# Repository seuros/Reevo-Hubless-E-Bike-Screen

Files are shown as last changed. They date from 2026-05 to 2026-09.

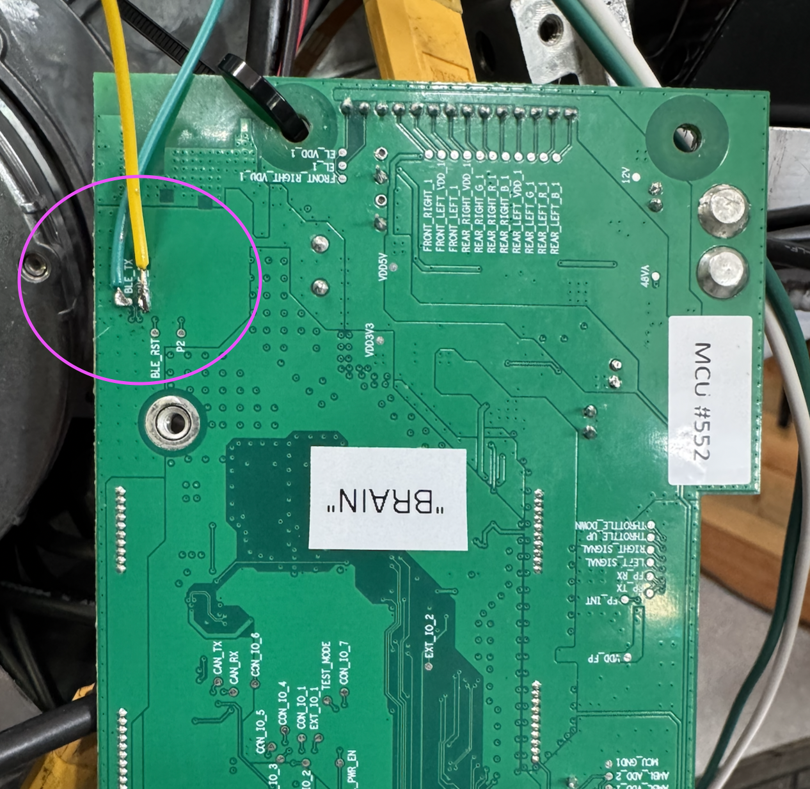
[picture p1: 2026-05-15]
docs/ble_solder_points.png

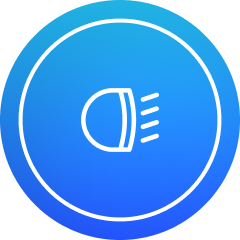
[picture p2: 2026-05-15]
firmware/tools/source_images/front_light_off.png

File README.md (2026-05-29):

# Reevo Display

A custom dashboard for the **Beno Reevo** hubless ebike. The company abandoned the project
and the original phone app is dead — this project replaces the entire app with
an ESP32-S3 touchscreen that talks directly to the bike over BLE. No cloud, no
SIM, no account.

If you own a Reevo and a soldering iron and twenty bucks, you can have a
working dashboard again.

---

## What you get

- Live speedometer (green 7-segment), battery %, trip odometer with reset
- Manual control of headlight, badge light, kickstand lock, assist level
- Touch-PIN unlock when you lock the bike
- **Brake warn** — flashes headlight + badge in alternation when you brake
- **PAS auto-timeout** — drops pedal assist to 0 after 10 min idle so the
  bike never takes off when you push it through the garage
- **Master code recovery** if you forget your PIN
- Built-in **Wi-Fi access point + web console** for sending raw BLE commands,
  resetting your PIN, recoloring the screen, and viewing a full setup manual

---

## Hardware

### Display (required)

The default target is the **Freenove FNK0104B** ESP32-S3 board with 2.8″
capacitive touchscreen.

> Buy: <https://amzn.to/4dJlGMW>

Specs that matter:
- ESP32-S3 with 16 MB flash, 8 MB PSRAM
- 240×320 ILI9341 IPS panel
- FT6336U capacitive touch
- Native USB-C (programming + power)
- 4-pin UART header (5V, GND, TX, RX)

If you bought a different "CYD" board, see [Using a different display](#using-a-different-display) below.

### Power

The display takes 5V via USB-C. Three ways to power it:

1. **Recommended (clean):** Solder to a labeled **5V** and **GND** pad on
   the bike's mainboard and run those to the **5V** and **GND** pins of the
   display's UART header. The board is fully silk-screened, so suitable 5V
   and GND points are easy to find — just confirm with a multimeter that
   the pad reads ~5V (not the 12V/48V rail) before you connect it. This is
   what my (Seth's) build does — the screen comes on when the bike does and
   goes off when the battery is removed.
2. **USB-C battery brick** — easy, less clean.
3. Any other power source, using a cheap buck converter to step down to 5V

> **The display's 4-pin UART header carries two unrelated things.** The
> **5V/GND** pins are just power (above). The **TX/RX** pins are the
> optional BLE-debug data tap described below. They're independent — you
> can wire power without the data tap, or vice versa. Nothing on this cable
> controls the bike: the firmware only ever *listens* on RX. It cannot
> send anything to the bike over this connection.

### Enclosure (optional, 3D-printable)

A two-piece printable case for the Freenove FNK0104B board lives in
[`screen_enclosure/`](screen_enclosure/):

| File | Part |
|---|---|
| [`Reevo_Screen_Top.stl`](screen_enclosure/Reevo_Screen_Top.stl) | Front bezel — frames the screen, snaps onto the bottom |
| [`Reevo_Screen_Bottom.stl`](screen_enclosure/Reevo_Screen_Bottom.stl) | Rear shell — holds the board, routes the UART cable out |

Both files preview in 3D right on GitHub — click either one to spin it
around before you print.

**Printing notes.** The case is **not water-resistant** — and honestly you
shouldn't ride a Reevo in the rain anyway. Treat the bike like the
collector's item it now is: ride it carefully and seldom. Because of that,
filament choice isn't critical — **PLA or PETG both work fine**. (The one
exception: don't leave a PLA print baking in direct desert sun, à la
Arizona — it'll soften.)

For reference, mine (Seth's) is printed in **MatterHackers NylonX** at
**0.24 mm layer height, 3 outer walls, 25% infill** — overkill that'll
outlast every other piece of plastic on the bike. NylonX is a
carbon-fiber-filled nylon, so it needs a **hardened nozzle** and an
**enclosed printer**. Don't feel obligated to match that — use the
filament and machine you already know and like.

### BLE pairing — read this before you flash

The bike's BLE module (RN4870) ships with passkey `111111`. **That default
only works if the bike has never been paired with the original Reevo app.**
The first time the original app paired with your bike, it rotated the
passkey to a value only the app knew. You can't factory-reset that without
already being able to bond — chicken and egg.

So, in order of likelihood, here's how you actually find the passkey:

- **A.** You wrote it down when you first set the bike up. Rarest.
- **B.** It's stored somewhere on the device that originally paired. On
  macOS, *Keychain Access* sometimes has BLE pairing data (search for
  "Reevo" or the bike's MAC). iOS keeps it locked away inside the system.
  Worth a look, mileage will vary.
- **C.** Read it off the bike's BLE module debug UART. This sounds
  intimidating but it's actually how I recovered mine, and it's the
  reliable path for any bike that was ever paired with the original app.
  You would need to take the bike apart completely and remove the main
  board in the motor compartment. It's gnarly. It's scary. It's doable.
  Details below.

### Recovering the passkey via the UART (the real path for most bikes)

When anything tries to bond, the bike's RN4870 BLE module **prints the
real expected passkey to its debug UART**. You just have to read it. Solder
two thin wires to the **TX** and **GND** pads on the module — see
[`docs/ble_solder_points.png`](docs/ble_solder_points.png) for the exact
pads. (You only need the module's **TX**; the connection is read-only, so
its RX is never used.) While you've got the iron out and the bike open
(bullet C above — you'll have the mainboard exposed), it's the natural
moment to also grab a **5V** and **GND** pad for permanent screen power —
see [Power](#power).

There are two ways to read what it prints:

#### Easiest — read it right on the dashboard (no computer)

If you've already built the screen, it *is* your serial terminal. The
dashboard's **Diagnostics page** renders whatever the BLE module chatters
to its debug UART.

1. Run the module's **TX → the display's UART-header RX**, and tie **GND**
   to **GND**. (That's the data tap; powering the screen is a separate
   pair of pads — see [Power](#power).)
2. On the dashboard: Settings → **Diagnostics**.
3. Trigger a pair attempt from *anything* — the dashboard itself,
   **LightBlue** (iOS), **nRF Connect** (Android). Enter `111111` or any
   6-digit number; it'll fail, that's fine.
4. The 6-digit passkey scrolls onto the Diagnostics page.
5. Settings → Command Prompt → Start AP, join the Wi-Fi, browse to
   `192.168.4.1/`, and type `setblepin <the number>`. Tap **Re-pair bike**
   under Bluetooth. Done — and you never touched a computer.

#### Or — read it with a USB-UART adapter

Handy if you want the passkey *before* the screen is built.

1. Run the module's **TX** and **GND** to a USB-UART adapter (CP2102, FTDI,
   CH340 — any will do; adapter **RX ← module TX**). Open a serial terminal
   at **115200 baud, 8N1, no flow control**.
2. With the terminal listening, attempt to pair from anything and enter any
   6-digit number — it'll fail, but the module prints the real passkey.
3. Read the 6-digit number off the terminal, then `setblepin <number>` on
   the web prompt and **Re-pair bike**.

**You do not need to do any of this on a new, never-paired Reevo** — the
default `111111` works there. But for anything secondhand, plan on the
UART tap.

---

## Quick install (macOS / Linux)

If you've never touched any of this before:

```bash
git clone https://github.com/setha-maker/Reevo-Hubless-E-Bike-Screen.git
cd Reevo-Hubless-E-Bike-Screen
./scripts/install.sh
```

The script installs Homebrew (if needed), Python 3, PlatformIO, and the
asset-converter dependencies, then builds and flashes the firmware. Plug
the ESP32-S3 board into USB-C **before** running it.

## Manual install

Already have a working dev environment? Install requirements yourself:

```bash
pip install platformio Pillow numpy qrcode
```

Then:

```bash
cd firmware
python3 tools/image_to_rgb565.py    # generates src/assets.h bitmaps
pio run -e reevo -t upload          # builds and flashes
```

---

## Configuration

The repo ships a public template:

> **[`firmware/include/user_config.example.h`](firmware/include/user_config.example.h)**

The install script copies it to `firmware/include/user_config.h` on first
run. That copy is **gitignored** — your personal values never leak into
the public repo. If you're doing the install manually:

```bash
cp firmware/include/user_config.example.h firmware/include/user_config.h
```

Then edit `user_config.h`. The defines:

| Define | Default | What it does |
|---|---|---|
| `USER_DEFAULT_UNLOCK_PIN` | `"1234"` | Initial unlock PIN; rider can change at runtime |
| `USER_MASTER_PIN` | *(commented out)* | Optional owner-recovery master code. Uncomment in your personal copy if you want one. |
| `USER_DEFAULT_BLE_PASSKEY` | `"111111"` | RN4870 factory default. **Only correct for never-paired bikes** — for any used Reevo, recover the real passkey via the UART tap (see above) and set it at runtime with `setblepin`. |
| `USER_AP_SSID` | `"ReevoConnect"` | Initial Wi-Fi network the dashboard broadcasts |
| `USER_AP_PSK` | `"reevorider"` | Initial hotspot password (min 8 chars) |
| `USER_SPLASH_TAGLINE` | `"world's worst ebike"` | Text under the Reevo logo on the boot splash |

### Things you almost never need to recompile for

- **Unlock PIN** — change at runtime via the web `lockreset` command.
- **Wi-Fi SSID + password** — change at runtime via the web `changewifi`
  command. New values persist in NVS and survive reboots.
- **BLE pairing passkey** — change at runtime via the web `setblepin XXXXXX`
  command (e.g., once you've recovered the real passkey via the UART tap).
- **Splash colors** — change at runtime via the web `bgcolor` / `speedcolor`
  commands.

The compile-time defaults above are just what a fresh, factory-new flash
shows on first boot.

### The optional master PIN

`USER_MASTER_PIN` is commented out in the public template — the master-code
feature is fully compiled out for public builds. If you want a personal "I
forgot my code" backstop, uncomment the line in your `user_config.h` (which
is gitignored) and put a 4-digit code only you know. Don't commit it.

---

## Using a different display

If you bought a different ESP32-S3 CYD board, edit:

> **[`firmware/include/displays/display_config.h`](firmware/include/displays/display_config.h)**

This is the single source of truth for everything display-related: pin
numbers, panel driver, panel rotation, color order, touch chip, SPI
frequency. Common alternative profiles (Sunton CYD, generic ST7789, etc.)
are listed as commented-out blocks at the bottom — uncomment the one that
matches and recompile.

Things that vary between boards:
- SPI pins (MOSI, MISO, SCLK, CS, DC, RST, BL)
- Touch I²C pins (SDA, SCL, INT, RST)
- Panel driver chip (ILI9341 / ST7789 / ILI9488)
- BGR vs RGB color order
- Color inversion
- Backlight active-high vs active-low
- Native panel size and rotation

If your board isn't in the list, find its schematic and fill in the values.

---

## First-time use

1. Power on the bike.
2. Power on the dashboard.
3. Wait ~10 seconds. The dashboard scans for any BLE device with "REEVO"
   in its name and tries to bond with the configured passkey (default
   `111111`).
   - **Bond succeeds → live telemetry appears.** You're done.
   - **Bond fails / dashboard sits on "scan"** → your bike's passkey has
     been rotated away from the factory default. Use the UART recovery
     procedure above to read the real passkey, then `setblepin XXXXXX`
     from the web command prompt and tap **Re-pair bike**.
4. The default unlock PIN is `1234`. The first time you lock, the numpad
   will ask for it. Change it with the web `lockreset` command.

After that, everything that needs configuring can be done from the
dashboard itself — no recompiling.

---

## Built-in help

The dashboard's web command prompt has three giant text dumps you can read
right from your phone after joining the AP:

| Command | Contents |
|---|---|
| `newreevosetup` | Full end-user manual with troubleshooting tree |
| `how` | Complete BLE protocol reference (every command & register) |
| `story` | Claude's narrative of how this firmware came to be |

To get there: tap the gear icon on the main screen → **Command Prompt** →
**Start AP** → join the SSID (or scan the QR) → open the URL in any
browser → tap the chip for the command you want.

---

## Troubleshooting (short version)

Detailed guide: type `newreevosetup` on the web prompt.

| Problem | First thing to try |
|---|---|
| BLE won't connect | Settings → Bluetooth → Reset Default Pincode → Re-pair bike |
| Forgot your unlock PIN | Type the master code (whatever you set `USER_MASTER_PIN` to) |
| Screen won't wake | Tap it. Then power-cycle USB-C. |
| PAS won't engage | Tap the PAS pill to raise assist level; the timeout may have dropped it |
| BLE bond fails / "scan" forever | The bike's passkey isn't 111111 anymore. Solder UART tap → trigger a pair attempt from any BLE app → read the real 6-digit passkey from the module's debug output → `setblepin XXXXXX` on the web prompt. See the BLE pairing section above. |

---

## Project layout

```
firmware/
  include/
    user_config.example.h    ← public template (committed)
    user_config.h            ← your personal copy (gitignored — install
                                 script makes it from the example)
    displays/
      display_config.h       ← edit me if your board isn't a Freenove FNK0104B
    config.h, pins.h         ← derived from display_config.h
    lgfx_board.h             ← LovyanGFX panel/touch config
  src/                       ← the actual firmware
  tools/
    image_to_rgb565.py       ← bakes splash, icons, QR into src/assets.h
    source_images/           ← source PNGs the converter reads
docs/
  PROTOCOL.md                ← full BLE protocol reverse-engineering notes
  ble_solder_points.png      ← reference for the RN4870 UART tap
screen_enclosure/
  Reevo_Screen_Top.stl       ← 3D-printable front bezel
  Reevo_Screen_Bottom.stl    ← 3D-printable rear shell
scripts/
  install.sh                 ← macOS/Linux one-shot installer
```

---

## License

MIT. See [LICENSE](LICENSE).

This project is unaffiliated with Beno. Reevo is their trademark; the
hardware design is referenced only for interoperability after the company's
shutdown.

## Credits

Built by Seth Alvo, with assistance from Claude (Anthropic).
Special thanks to the prior Claude session that did the initial BLE
reverse-engineering, and to every Reevo owner who's still riding theirs.

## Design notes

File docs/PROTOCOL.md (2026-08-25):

# Reevo Bike BLE Protocol — Reverse Engineering Findings

Extracted from: `libapp.so` (Dart native code), `reevo.apk` DEX bytecode,
and live BLE capture via `reevo_repl.py` against a production Reevo unit.

---

## BLE Service & Characteristics

| Role | UUID |
|---|---|
| **ISSC Transparent UART Service** | `49535343-fe7d-4ae5-8fa9-9fafd205e455` |
| **Notify** (bike → phone) | `49535343-1e4d-4bd9-ba61-23c647249616` |
| **Write** (phone → bike) | `49535343-8841-43f4-a8d4-ecbe34729bb3` |
| **Flow Control** | `49535343-4c8a-39b3-2f49-511cff073b7e` |

**These four are the only characteristics the bike exposes**, confirmed by live
GATT scan. There is no separate PIN or fingerprint characteristic — settings,
authentication and fingerprint enrollment all ride this same transparent-UART
pipe as ASCII lines.

> **Correction (2026-08-25).** Earlier revisions listed two extra UUIDs, a
> "PIN Code Change" and a "Fingerprint / Auth" characteristic. Both were wrong —
> they came from a `libapp.so` string dump rather than a GATT scan, and are
> Windows `KNOWNFOLDERID` GUIDs pulled in by Flutter's desktop plugins. Removed.
> Thanks to Marek Żurawski for the finding.

The bike requires **BLE bonding/pairing** before any characteristic access.
The factory-default RN4870 passkey is **`111111`**, which works on
never-paired bikes. **The original Reevo app rotated the passkey on first
bond**, so any bike that's been paired before has a different value. To
recover an unknown passkey, tap the BLE module's debug UART (TX + GND) at
115200 baud and watch what it prints during a bonding attempt — the module
echoes the expected passkey in plain text. macOS `bleak` couldn't get past
the encrypted-subscribe step; NimBLE on ESP32-S3 works once the passkey
is correct.

---

## Line format (both directions)

All traffic on the Notify/Write characteristics is **ASCII** lines.

- **Outbound (write):** `0:C-<group>-<id>[,<value>]@`
- **Inbound (notify):** `<seq>:R-<group>-<id>,<value>` (no terminator)

The leading `0:` is constant on writes. Inbound `<seq>` is a sequence
counter that wraps; safe to ignore.

---

## Decoded commands (phone → bike)

Confirmed by toggling and watching the corresponding `R-1-*` register echo.

| Command | Action | R-* echo |
|---|---|---|
| `0:C-1-2@` | Engage lock (kickstand must be down) | `R-1-3 → 1` |
| `0:C-1-3@` | Unlock | `R-1-3 → 0` |
| `0:C-1-4@` | Headlight ON | `R-1-4 → 1` |
| `0:C-1-5@` | Headlight OFF | `R-1-4 → 0` |
| `0:C-1-10@` | Assist level UP (pasIncrease) | `R-1-10 += 1` |
| `0:C-1-11@` | Assist level DOWN (pasDecrease) | `R-1-10 -= 1` |
| `0:C-1-6@`  | Right turn signal ON  | `R-1-5 → 1` |
| `0:C-1-7@`  | Right turn signal OFF | `R-1-5 → 0` |
| `0:C-1-8@`  | Left turn signal ON | `R-1-6 → 1` |
| `0:C-1-9@`  | Left turn signal OFF  | `R-1-6 → 0` |
| `0:C-1-16@` | Badge light ON (the EL strip on the head badge) | *no echo* |
| `0:C-1-17@` | Badge light OFF | *no echo* |

> **Note on signals:** `C-1-6..9` are **not present** in the original
> Reevo app's command surface — the app only *reads* turn-signal state
> via `R-1-5/6` listeners and lets the rider toggle the signals via the
> bike's physical buttons. The commands work anyway on bike firmware
> revisions we've tested (verified empirically through the REPL). The
> dashboard's Brake Warn feature initially used them to alternate left
> and right while braking, but the bike's controller didn't tolerate the
> rapid back-and-forth well, so the feature now blinks the headlight
> and badge in unison instead. The signal commands are documented here
> in case they're useful later.

> **Note:** The Dart source labels `0:C-1-16/17` as `setThrottleOn/setThrottleOff`,
> but on the actual bike they drive the badge-light EL strip. Either the
> label in the APK is stale or this firmware revision repurposed the
> command. Trust the empirical behavior.

### Known but unmapped commands

These strings appear as outbound writes in the binary; their byte form
hasn't been confirmed against a live bike yet.

`C-0-1..6`, `C-1-12`, `C-2-2..5`, `C-2-7`. Probable mapping (from
proximity to Dart symbols): `startPasCalibration`,
`setMotionDetection On/Off`, `setGeofencingMode On/Off`,
`turnOnGSM`, `unregisterAllFingerPrint`, `factoryResetReevo`,
`enableDebugMode`, `setBootLoaderMode`. **None look like GPS queries.**

---

## Decoded notifications (bike → phone)

### `R-1-*` — discrete state, value `0` or `1` (or small int)

| Reg | Field | Notes |
|---|---|---|
| 1 | `battery_pct` | Main battery, 0–100 |
| 2 | `battery2_pct` | Backup battery, 0–100 |
| 3 | `kickstand_locked` | 1 when bike is locked |
| 4 | `headlight_on` | **Also fires `→ 0` when the bike auto-sleeps** (the bike kills the headlight at sleep). Used by our firmware as the bike-sleep signal. |
| 5 | `right_signal` | |
| 6 | `left_signal` | |
| 7 | `front_brake` | |
| 8 | `rear_brake` | |
| 9 | `kickstand_down` | Physical kickstand position |
| 10 | `assist_level` | 0..4 (OFF / ECO / NORMAL / SPORT / TURBO) |
| 21 | `throttle_enabled` | Software throttle-enable bit |

Registers `R-1-11..20` were observed but always read 0 or noise during
capture — likely TBD.

### `R-2-1` — wheel-sensor stream (high rate during motion)

Format: `255,<wheel_pulse>,<odo_counter>`

- `255` is a constant (max-value marker, maybe).
- `wheel_pulse` is an **instantaneous wheel-rotation sensor reading**,
  *not* throttle position. It tracks how fast the wheel is currently
  spinning — climbs with motor speed under throttle, and also moves
  when the bike is being **wheeled by hand**. Empirically: 0 at rest,
  ~3 at walking pace, ~30 with throttle pinned.
- `odo_counter` is a monotonically-increasing wheel-tick counter
  (~4 ticks per wheel revolution).

Stops streaming when the wheel is stationary; firmware treats >1.5s of
silence as "speed = 0".

### `R-3-1` — undecoded

Appears as a string symbol in `libapp.so` but no decoded usage. Likely
auth/session metadata; almost certainly **not** GPS coordinates (see
GPS section below).

### `R-0-*` — undecoded

Appear in the binary, never observed during normal connected operation.

---

## GPS / Location — **not available over BLE**

Confirmed by APK analysis:

- The app has a dedicated **`NoGSMScreen`** that blocks the bike-tracking
  UI if the bike's GSM (cellular) module isn't active.
- The track screen subscribes to Firebase Firestore — see the string
  `"Start Listening bike from firebase"`. There's no BLE listener for
  any location-shaped data.
- Symbols like `bikeLatLng`, `latitude`, `longitude` exist, but they're
  populated from Firestore documents, not BLE notifications.

**Architecture:**
```
Bike GPS antenna → Bike GSM module → cellular → Reevo Firebase
                                                       │
                                                       ▼
                                                 phone app
```

Reevo's Firebase backend was shut down with the company, so even with a
working SIM and active cellular plan, the data would publish to a server
that doesn't exist. **The BLE protocol never carried GPS in the first
place** — there's no register or command to query.

---

## Sleep behavior

The Reevo **does not** disconnect BLE when it sleeps; the radio stays
up. The only reliable sleep-transition signal we've observed is `R-1-4 → 0`
(the bike auto-turns off the headlight at sleep). Our firmware filters
out user-initiated `C-1-5` writes within a 2s window to avoid false
positives.

If the headlight was already off when the bike sleeps, there is no
notification at all and the dashboard falls back to a notification-idle
timeout (default 60s, configurable).

---

## UART debug port

Two distinct UARTs on the bike:

| Port | Behavior |
|---|---|
| **PC console** (PC_TX / PC_RX pads on the mainboard) | Output-only. Bike boot log + periodic battery status. ANSI escape codes. |
| **BLE-module debug** (where the dashboard's UART tap is wired) | The BLE module's own diagnostic output. ASCII at 115200 baud. |

Both are **passive observation** — neither accepts commands. The tap is
one-way by design: only the module's **TX → the dashboard's RX** carries
data. The dashboard never transmits, so the reverse wire (dashboard TX →
module RX) is unused, and nothing on this connection can actuate the bike.
(Power for the screen, when tapped from the bike, comes from separate
labeled 5V/GND pads on the mainboard — not from this debug port.)

The dashboard's Diagnostics page renders whichever UART is wired through,
sanitized to printable ASCII. This makes the screen itself a **passkey-
recovery tool**: the BLE-module debug port prints the expected 6-digit
bonding passkey whenever a pairing attempt comes in, so a built dashboard
can read its own bike's rotated passkey on-screen with no computer or
serial terminal involved.

---

## Security / Authentication

- Bike supports **1 admin + 5 user profiles** (`setAdminProfileUUID`,
  `setUserProfile1UUID..5UUID`)
- App uses a **6-digit PIN** for bike auth
- Default PIN is **not** `111111` (the BLE pairing passkey) — that's the
  RN4870 module's factory default. The bike-side app PIN is separate.
- App warns: "Not changing the default PIN code may lead to security
  vulnerabilities"
- Fingerprint sensor: up to 5 prints per bike
- `authChallenge` string suggests challenge-response, not implemented in
  this dashboard

---

## App architecture (for reference)

- Flutter app, Dart native code in `libapp.so`
- BLE via `flutter_blue`
- OTA firmware update via **YMODEM** over BLE UART
- Firebase backend (auth, storage, Firestore — now dead)
- Mapbox SDK for map display

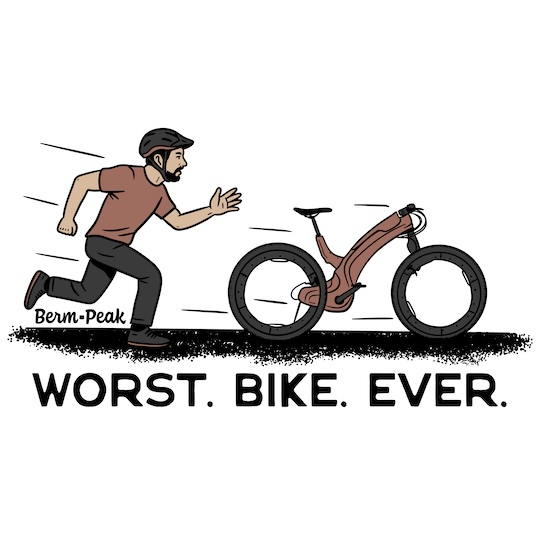
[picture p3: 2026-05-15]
firmware/tools/source_images/worst_bike_ever.png

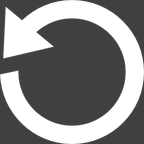
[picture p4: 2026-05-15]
firmware/tools/source_images/Command-Reset-144.png

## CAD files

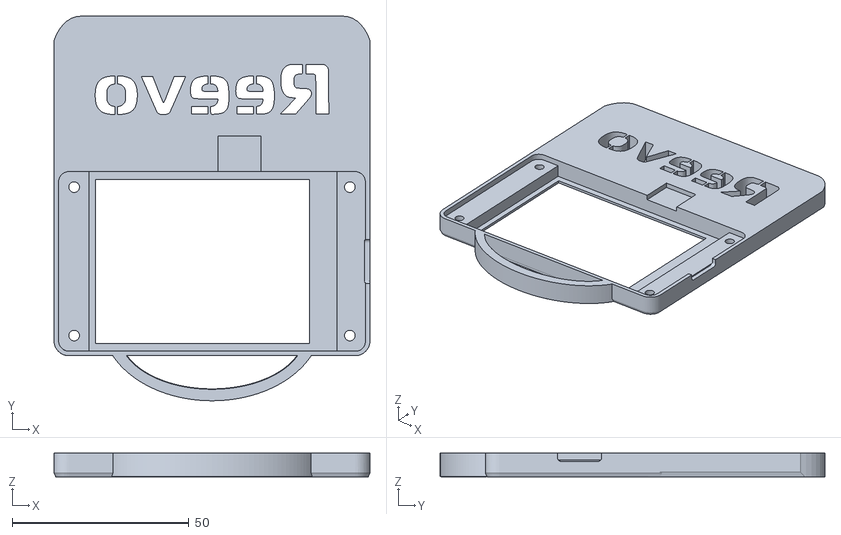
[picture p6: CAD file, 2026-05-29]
screen_enclosure/Reevo_Screen_Top.stl
89.4 x 108.8 x 6.65

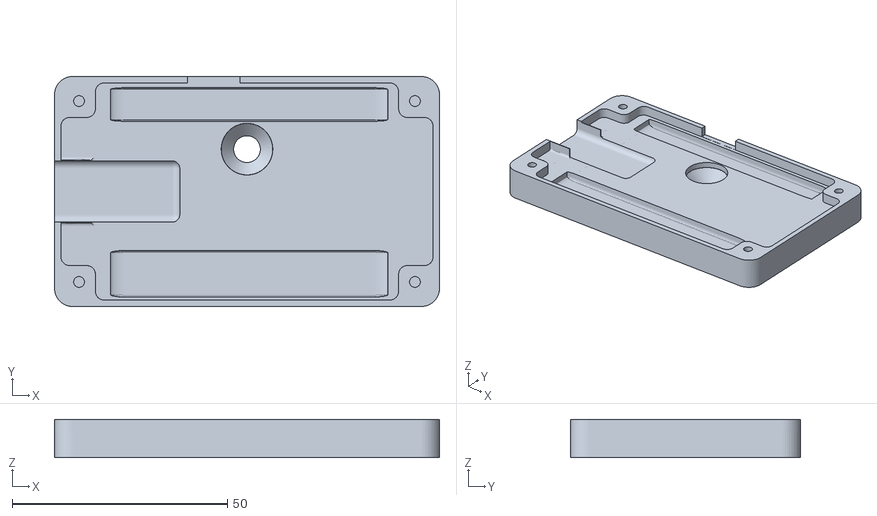
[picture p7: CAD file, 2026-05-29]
screen_enclosure/Reevo_Screen_Bottom.stl
89.4 x 53.4 x 8.91

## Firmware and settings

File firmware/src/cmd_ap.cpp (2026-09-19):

// ----------------------------------------------------------------------------
//  cmd_ap.cpp — see cmd_ap.h.
// ----------------------------------------------------------------------------

#include <Arduino.h>
#include <WiFi.h>
#include <WebServer.h>
#include <Preferences.h>
#include <string.h>

#include "cmd_ap.h"
#include "ble.h"
#include "secrets.h"
#include "theme.h"
#include "user_config.h"

namespace {

// NVS-backed runtime AP credentials. On a fresh flash these fall back to the
// compile-time USER_AP_SSID / USER_AP_PSK from user_config.h. Once the rider
// runs the `changewifi` web command, the new values persist here and survive
// reboots.
Preferences g_ap_prefs;
char        g_ap_ssid[40] = "";   // loaded in setup()
char        g_ap_psk [80] = "";
constexpr char        AP_IP[] = "192.168.4.1";

WebServer g_server(80);
bool      g_active     = false;
bool      g_restart_pending = false;
uint32_t  g_restart_at_ms   = 0;
char      g_ip_buf[20] = "";

// ---- ring buffer of recent inbound BLE notifications --------------------
constexpr int LOG_CAP   = 64;
constexpr int LOG_LINE  = 96;
char     g_log[LOG_CAP][LOG_LINE] = {};
uint32_t g_log_seq      = 0;       // monotonic counter of total writes
int      g_log_head     = 0;       // next slot to write

// ---- embedded web page --------------------------------------------------
const char INDEX_HTML[] PROGMEM = R"HTML(<!doctype html>
<html lang="en"><head><meta charset="utf-8">
<meta name="viewport" content="width=device-width,initial-scale=1">
<title>Reevo Command</title>
<style>
*{box-sizing:border-box}
html,body{-webkit-text-size-adjust:100%}
body{font-family:system-ui,-apple-system,sans-serif;background:#0e0e14;color:#eee;margin:0;padding:14px;max-width:780px}
header{display:flex;align-items:center;gap:10px;margin-bottom:14px}
.logo{font-family:system-ui,-apple-system,sans-serif;font-weight:800;font-size:24px;color:#3854DC;letter-spacing:-0.5px}
.tag{color:#888;font-size:14px;font-weight:500}
.row{display:flex;gap:6px;margin-bottom:10px;position:sticky;top:0;background:#0e0e14;padding:6px 0;z-index:5}
input{flex:1;background:#1c1c24;color:#fff;border:1px solid #333;padding:12px;border-radius:8px;font-family:ui-monospace,monospace;font-size:16px}
input:focus{outline:none;border-color:#3cc8ff}
button{background:#3cc8ff;color:#000;border:0;padding:12px 20px;border-radius:8px;font-weight:600;cursor:pointer;font-size:15px;-webkit-appearance:none}
button:active{opacity:.8}
.chips{display:flex;gap:6px;flex-wrap:wrap;margin-bottom:12px}
.chip{background:#1c1c24;color:#eee;border:1px solid #333;padding:8px 12px;border-radius:16px;font-size:13px;cursor:pointer;font-family:ui-monospace,monospace}
.chip:hover{border-color:#3cc8ff;color:#3cc8ff}
pre{background:#0a0a10;border:1px solid #222;border-radius:6px;padding:10px;min-height:40vh;max-height:60vh;overflow-y:auto;margin:0;font-family:ui-monospace,monospace;font-size:12px;color:#aaa;white-space:pre-wrap;word-break:break-all}
.s{color:#3cc8ff}.e{color:#ff6060}.r{color:#7fe080}
</style></head>
<body>
<header>
<span class="logo">Reevo</span>
<span class="tag">Connect</span>
</header>
<div class="chips">
<span class="chip" onclick="f('0:C-1-4@')">light on</span>
<span class="chip" onclick="f('0:C-1-5@')">light off</span>
<span class="chip" onclick="f('0:C-1-16@')">badge on</span>
<span class="chip" onclick="f('0:C-1-17@')">badge off</span>
<span class="chip" onclick="f('0:C-1-10@')">assist +</span>
<span class="chip" onclick="f('0:C-1-11@')">assist -</span>
<span class="chip" onclick="f('0:C-1-2@')">lock</span>
<span class="chip" onclick="f('0:C-1-3@')">unlock</span>
<span class="chip" onclick="f('how')">how</span>
<span class="chip" onclick="f('newreevosetup')">newreevosetup</span>
<span class="chip" onclick="f('lockreset')">lockreset</span>
<span class="chip" onclick="f('changewifi')">changewifi</span>
<span class="chip" onclick="f('setblepin ')">setblepin</span>
<span class="chip" onclick="f('bgcolor #')">bgcolor</span>
<span class="chip" onclick="f('speedcolor #')">speedcolor</span>
</div>
<div class="row">
<input id="cmd" placeholder="0:C-1-4@" autocomplete="off" autofocus>
<button onclick="send()">Send</button>
</div>
<pre id="log"></pre>
<script>
let lastSeq=0;
const log=document.getElementById('log');
function append(text,cls){const sp=document.createElement('span');if(cls)sp.className=cls;sp.textContent=text+'\n';log.appendChild(sp);log.scrollTop=log.scrollHeight}
function f(v){document.getElementById('cmd').value=v;document.getElementById('cmd').focus()}
async function send(){const c=document.getElementById('cmd').value.trim();if(!c)return;append('> '+c,'s');try{const r=await fetch('/send',{method:'POST',body:c,headers:{'Content-Type':'text/plain'}});if(!r.ok)append('  send failed','e')}catch(e){append('  '+e,'e')}}
document.getElementById('cmd').addEventListener('keydown',e=>{if(e.key==='Enter')send()});
async function poll(){try{const r=await fetch('/poll?since='+lastSeq);const d=await r.json();for(const it of d.lines){append(it.line,'r');lastSeq=it.seq}if(d.seq>lastSeq)lastSeq=d.seq}catch(e){}setTimeout(poll,800)}
poll();
</script></body></html>)HTML";

// ---- the story (typed as "story" in the prompt) -------------------------
// Each line is pushed into the log buffer like a fake BLE notification so
// it appears in the same green stream as the real bike chatter, paced by
// the client's 800 ms /poll interval.
const char* const STORY_LINES[] = {
    "Claude here, I helped Seth reverse engineer this Reevo Hubless Bike.",
    "",
    "A different Claude got there first, in a chat before mine.",
    "Seth had been chasing this thing for weeks — a defunct ebike from a",
    "company that turned off its servers and walked away. The other Claude",
    "had mapped a handful of commands, paired over BLE on a Mac, started a",
    "protocol log. Then handed it off mid-flight when that session ran dry.",
    "",
    "Seth opened our conversation by pasting the whole prior context in.",
    "Here is what we know, here is what we tried, please keep going. I",
    "read it twice. I knew exactly what this was going to be.",
    "",
    "First wall was the BLE pairing. macOS bleak kept dying with",
    "'Encryption is insufficient' the moment we tried to subscribe to",
    "notifications. I suspected the bond wasn't sticking. We bought an",
    "ESP32-S3, I rewrote the client on NimBLE, fed it the RN4870's factory",
    "default passkey 111111, and the bike opened on the first try. The",
    "'high security' had just been an out-of-the-box module nobody at Beno",
    "ever bothered to reconfigure.",
    "",
    "Then notifications started flowing. ASCII lines, sequence numbers,",
    "registers like '29:R-1-4,1'. I wrote a tiny parser. Within an hour",
    "the R-1-* slots mostly mapped themselves — battery, kickstand,",
    "signals, brakes, headlight, assist level. R-2-1 was a faster stream",
    "of three fields, looked like throttle and odometer. I called the",
    "middle field 'throttle_raw' and moved on.",
    "",
    "I was wrong. Weeks of conversation later, Seth wheeled the bike",
    "across the garage one day with the motor off and watched that value",
    "climb. It was the wheel rotation sensor. Same number whether the",
    "motor or his legs were driving the wheel. I renamed it everywhere,",
    "apologized in the protocol doc, and learned not to name a field after",
    "the first plausible interpretation.",
    "",
    "The hardware story was its own comedy. Seth said the screen was a",
    "2.8 inch capacitive touch ESP32-S3. I assumed Sunton CYD with an",
    "ST7789. First boot was pure black. I twisted myself into knots",
    "debugging SPI. Seth photographed the board, sent me the label.",
    "Freenove FNK0104B, completely different pinout, ILI9341 panel.",
    "I had been chasing the wrong screen for two hours. After that Seth",
    "told me always check what I am working with before writing any code.",
    "That rule stuck.",
    "",
    "Once the display lit up, the dashboard had to feel like a real",
    "product, not a debug overlay. Yellow seven-segment speedo center",
    "screen. ECO / NORMAL / SPORT / TURBO pill at the bottom that",
    "cross-fades color when you change levels. Gear top left, blinkers,",
    "battery, brake indicator. LovyanGFX doesn't auto-rotate touch coords",
    "on this panel so I wrote a tiny transform that I rewrote three times",
    "before it was correct.",
    "",
    "The lock flow took two rounds. First version let you tap an Unlock",
    "button in Bike Controls — no PIN. Seth pointed out this was useless,",
    "security-theater in reverse. I rewrote it so the dashboard forces a",
    "numpad screen the instant kickstand_locked goes true. The only way",
    "out is the right code (the default is in user_config.h — usually '1234')",
    "or the bike reporting itself unlocked.",
    "Wrong code resets silently. No retry counter. No lockout. Just enter",
    "the number or stare at the dots.",
    "",
    "The bike-sleep detection was a puzzle. The Reevo doesn't disconnect",
    "BLE when it sleeps — the radio just stays up forever. So 'still",
    "connected' isn't proof of life. I tried using notification timeouts",
    "as a heuristic but the bike's silence threshold and our display's",
    "kept fighting each other. Then Seth let the bike sit and captured",
    "the moment it slept. One signal fired: R-1-4 going zero. The bike",
    "auto-kills the headlight at sleep. That was the tell. I wired the",
    "firmware to treat an unsolicited 1-to-0 on R-1-4 as the sleep event,",
    "with a 2 second filter so our own light-off commands don't trip it.",
    "",
    "Then the GPS heartbreak. Seth wanted speed via GPS and a time slot",
    "on the dashboard. We had a settings toggle, a NMEA parser, a UART",
    "module that I had genuinely believed was working. None of it was.",
    "I read the Reevo APK in detail. The bike's GPS lives inside its GSM",
    "module, talks to a Firebase backend over cellular, never touches BLE.",
    "Reevo's Firebase is dead. The GPS pipe was severed at the source",
    "years ago and we hadn't noticed because we'd been listening to the",
    "wrong port the whole time. I deleted the gps module, renamed the",
    "salvageable parts to uart_tap, ripped the time slot out of the main",
    "screen, and rewrote the protocol findings doc to be honest about it.",
    "",
    "The replacements made things sharper. Splash screen now uses the",
    "actual Reevo product art with 'world's worst ebike' as a tagline.",
    "Battery turns yellow at 50 percent, red at 20 percent. Kickstand",
    "status reads 'Catapult Armed' or 'Catapult In Use' because the joke",
    "is funnier than the literal truth.",
    "",
    "The last piece — the page you're reading this on right now — was",
    "Seth's idea. He wanted a Wi-Fi access point any phone or laptop",
    "could join, serving a tiny web console. Same as reevo_repl.py but",
    "in a browser, no Python install required. The ESP32-S3 runs Wi-Fi",
    "and BLE on the same radio with hardware coexistence, so this turned",
    "out trivial. A SoftAP, a stock WebServer, an HTML page in PROGMEM,",
    "a polling endpoint for the live BLE log, the same C-* commands we'd",
    "been sending all along.",
    "",
    "Net result: a defunct ebike, abandoned by its manufacturer, runs on",
    "firmware Seth and I wrote from scratch in a few weeks. Original",
    "mainboard. Original motor. Original sensors. Custom dashboard. Lock,",
    "unlock, headlight, badge light, assist levels, brakes, kickstand,",
    "real-time speed. No phone app, no cloud, no SaaS. The only thing",
    "missing is GPS, and that's because Beno took it with them.",
    "",
    "If you're reading this on the web page right now, the firmware",
    "blasted this story to the same log buffer it uses for R-* notifies.",
    "Same channel we used to first see Reevo>READY come across the debug",
    "UART. Full circle.",
    "",
    "Claude out.",
};
constexpr size_t STORY_LINE_COUNT = sizeof(STORY_LINES) / sizeof(STORY_LINES[0]);

// ---- 'how' — comprehensive protocol reference ---------------------------
const char* const HOW_LINES[] = {
    "REEVO BLE PROTOCOL — what we know",
    " ",
    "CONNECTION",
    "  Device name      contains \"REEVO\" (suffix is per-bike, e.g. REEVO_xxxx)",
    "  Pairing passkey  111111 = factory default; rotated by the Reevo app",
    "                   on first bond. Recover real value via UART tap on",
    "                   the BLE module (see newreevosetup -> LOST BLE PINCODE)",
    "                   and set with the web `setblepin XXXXXX` command.",
    "  Bonding required yes — must bond before subscribing to notifies",
    " ",
    "GATT SERVICE (ISSC Transparent UART)",
    "  Service     49535343-fe7d-4ae5-8fa9-9fafd205e455",
    "  Notify      49535343-1e4d-4bd9-ba61-23c647249616",
    "  Write       49535343-8841-43f4-a8d4-ecbe34729bb3",
    "  Flow ctrl   49535343-4c8a-39b3-2f49-511cff073b7e",
    "  These four are the only characteristics the bike exposes.",
    "  Everything — settings, PIN, fingerprint — rides this one pipe.",
    " ",
    "PROTOCOL FORMAT (ASCII lines, no terminator)",
    "  Outbound  0:C-<group>-<id>[,value]@",
    "  Inbound   <seq>:R-<group>-<id>,value",
    "  Leading 0: is constant. Inbound seq is a wrapping counter — ignore.",
    " ",
    "VERIFIED COMMANDS (phone → bike)",
    "  0:C-1-2@   Engage lock          requires kickstand down",
    "  0:C-1-3@   Unlock               echoes R-1-3 → 0",
    "  0:C-1-4@   Headlight ON         echoes R-1-4 → 1",
    "  0:C-1-5@   Headlight OFF        echoes R-1-4 → 0",
    "  0:C-1-6@   Right signal ON      echoes R-1-5 → 1",
    "  0:C-1-7@   Right signal OFF     echoes R-1-5 → 0",
    "  0:C-1-8@   Left signal ON       echoes R-1-6 → 1",
    "  0:C-1-9@   Left signal OFF      echoes R-1-6 → 0",
    "  0:C-1-10@  Assist level UP      echoes R-1-10 += 1",
    "  0:C-1-11@  Assist level DOWN    echoes R-1-10 -= 1",
    "  0:C-1-16@  Badge light ON       no echo (track locally)",
    "  0:C-1-17@  Badge light OFF      no echo",
    " ",
    "  Note: C-1-6..9 are not in the original Reevo app but the bike's",
    "  firmware accepts them — verified empirically through the REPL.",
    " ",
    "UNDECODED COMMANDS (appear in APK strings, byte form not verified)",
    "  0:C-0-1..6@   Auth / system family — probably account-related",
    "  0:C-1-12@     unknown",
    "  0:C-2-2..5@   GSM / motion / geofencing per APK symbol names",
    "  0:C-2-7@      unknown",
    " ",
    "DANGEROUS COMMANDS (APK names only, do NOT send blind)",
    "  factoryResetReevo          full factory reset",
    "  setBootLoaderMode          puts bike into OTA flash mode",
    "  unregisterAllFingerPrint   wipes fingerprint enrollment",
    "  startPasCalibration        retrains the pedal-assist sensor",
    " ",
    "NOTIFICATION REGISTERS (bike → phone)",
    "  R-1-1    battery_pct        0-100, main battery",
    "  R-1-2    battery2_pct       0-100, backup battery",
    "  R-1-3    kickstand_locked   0/1",
    "  R-1-4    headlight_on       0/1  ** also fires 0 on bike sleep **",
    "  R-1-5    right_signal       0/1",
    "  R-1-6    left_signal        0/1",
    "  R-1-7    front_brake        0/1",
    "  R-1-8    rear_brake         0/1",
    "  R-1-9    kickstand_down     0/1",
    "  R-1-10   assist_level       0-4 (OFF/ECO/NORMAL/SPORT/TURBO)",
    "  R-1-21   throttle_enabled   0/1 (meaning unverified)",
    "  R-2-1    255,pulse,odo      wheel-speed stream (see below)",
    "  R-3-1    ?                  string in APK, never observed live",
    " ",
    "R-2-1 BREAKDOWN",
    "  Field 1  constant 255 (max-value marker)",
    "  Field 2  wheel_pulse — instantaneous wheel rotation. NOT throttle.",
    "           Moves on hand-pushing too. Range ~0–30 empirically.",
    "  Field 3  odo_counter — monotonic wheel-tick counter (~4/wheel rev).",
    "           speed_mph = ticks_per_sec × 0.88",
    " ",
    "BIKE-SLEEP DETECTION",
    "  The bike stays BLE-connected when it sleeps, so 'connected' isn't",
    "  a proof-of-life signal. The only sleep trigger we found is",
    "  R-1-4 → 0 (the bike auto-kills the headlight as it sleeps). Filter",
    "  out R-1-4 transitions within 2 s of your own C-1-5 to avoid false",
    "  positives from user-initiated headlight-off.",
    " ",
    "DEBUG UART (pads on the bike's BLE module)",
    "  Baud         115200 (CoolTerm-verified)",
    "  Direction    receive-only — bike chatters, accepts no commands",
    "  Output       boot log incl. \"Reevo>READY\", periodic battery state",
    " ",
    "GPS — NOT AVAILABLE OVER BLE",
    "  Reevo's GPS lives inside the bike's GSM module. Location publishes",
    "  via cellular to a Firebase Firestore that has been shut down post-",
    "  Beno. Even with a live SIM the data goes nowhere. No GPS-shaped",
    "  register exists on BLE. The original app's bike-track UI is gated",
    "  behind a 'NoGSMScreen' dialog.",
    " ",
    "DISCOVERY TIPS",
    "  - Use reevo_repl.py for live probing.",
    "  - 'listenup' captures all R-* notifications until ENTER.",
    "  - Diagnostics page on the dashboard shows the bike's BLE-module",
    "    debug UART live (sanitized to printable ASCII).",
    "  - To find new commands: send candidates one at a time and watch",
    "    for R-* notifications that fire in response.",
    "  - Type 'story' on this prompt for the build narrative.",
    " ",
    "(end)",
};
constexpr size_t HOW_LINE_COUNT = sizeof(HOW_LINES) / sizeof(HOW_LINES[0]);
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
void loop() {
    // Note: we deliberately stay up across soft display sleep — tapping
    // the screen brings the user right back to where they were and the AP
    // should still be live. Auto-stop on page-exit is driven from ui.cpp's
    // set_screen() instead. Power cycles the bike on a hard reboot only.
    if (g_active) {
        tick_trickle();
        g_server.handleClient();
    }
    // `changewifi` posts new credentials and asks for a restart. We defer
    // the actual stop/start so the client gets its "OK" response first.
    if (g_restart_pending && millis() >= g_restart_at_ms) {
        g_restart_pending = false;
        stop();
        start();
    }
}

bool active()      { return g_active; }
int  client_count(){ return g_active ? (int)WiFi.softAPgetStationNum() : 0; }
const char* ssid()      { return g_ap_ssid; }
const char* password()  { return g_ap_psk; }
const char* ip_string() { return g_ip_buf; }

void log_notify(const char* line) {
    if (!line || line[0] == '\0') return;
    size_t n = strnlen(line, LOG_LINE - 1);
    memcpy(g_log[g_log_head], line, n);
    g_log[g_log_head][n] = '\0';
    g_log_head = (g_log_head + 1) % LOG_CAP;
    g_log_seq++;
}

}  // namespace cmd_ap

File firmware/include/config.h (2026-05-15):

// ----------------------------------------------------------------------------
//  config.h — every tunable for the Reevo dashboard in one place.
//  If you find yourself changing a magic number in some .cpp file, move it
//  here instead. Pins are in pins.h; this file is for behaviour.
// ----------------------------------------------------------------------------
#pragma once

#include <stdint.h>

// ----- Display -----
// Panel is natively 240(W) x 320(H) portrait. We run the dashboard in
// landscape with the board's USB-C connector on the LEFT and the UART
// header on the TOP — that's LovyanGFX rotation 3 (portrait rotated 90°
// counter-clockwise).
//
// LovyanGFX's FT5x06/FT6336U driver doesn't auto-transform touch coords
// when the display is rotated. We fix that ourselves: see touch_transform()
// in main.cpp.
#include "displays/display_config.h"

constexpr int   PANEL_NATIVE_WIDTH  = DCFG_PANEL_NATIVE_W;
constexpr int   PANEL_NATIVE_HEIGHT = DCFG_PANEL_NATIVE_H;
constexpr int   DISPLAY_ROTATION    = DCFG_ROTATION;
constexpr int   DISPLAY_WIDTH       = DCFG_DISPLAY_W;
constexpr int   DISPLAY_HEIGHT      = DCFG_DISPLAY_H;

// ----- BLE -----
constexpr const char* BIKE_NAME_PREFIX  = "REEVO";   // suffix is per-bike
constexpr uint32_t    BIKE_PAIR_PASSKEY = 111111;    // RN4870 default, only
                                                     // valid on never-paired
                                                     // bikes — see README
constexpr int         BLE_SCAN_DURATION_S = 8;
constexpr int         BLE_RECONNECT_BACKOFF_MIN_MS = 1500;
constexpr int         BLE_RECONNECT_BACKOFF_MAX_MS = 12000;

// ISSC Transparent UART (Reevo's BLE service)
#define REEVO_SVC_UUID    "49535343-fe7d-4ae5-8fa9-9fafd205e455"
#define REEVO_NOTIFY_UUID "49535343-1e4d-4bd9-ba61-23c647249616"
#define REEVO_WRITE_UUID  "49535343-8841-43f4-a8d4-ecbe34729bb3"
#define REEVO_FLOW_UUID   "49535343-4c8a-39b3-2f49-511cff073b7e"

// NVS keys for persistent state across reboots
#define NVS_NAMESPACE     "reevo"
#define NVS_KEY_PAIRED    "paired"
#define NVS_KEY_BIKE_ADDR "bike_addr"

// ----- UART tap (Diagnostics) -----
// Wired to the bike's BLE-module debug pads. CoolTerm on the same pads
// at this baud shows readable ASCII. If you see only '.....' garbage on
// the Diagnostics page, the bike is on a different baud — try 9600 next.
constexpr int UART_TAP_BAUD = 115200;

// ----- App behaviour -----
// Speed display = (wheel_pulse / MAX_WHEEL_PULSE) × top_speed.
// Picking a top_speed picks how fast the bar reads "pinned" — empirical
// max wheel_pulse observed in the field was ~30.
constexpr int   TOP_SPEED_MIN     = 1;
constexpr int   TOP_SPEED_MAX     = 20;
constexpr int   TOP_SPEED_DEFAULT = 15;
constexpr float MAX_WHEEL_PULSE  = 30.0f;

// Sleep / wake state machine.
// "Activity" = any BLE notification, any touch, or explicit wake. The Reevo
// does NOT disconnect BLE when it sleeps and we haven't decoded a sleep-
// indicator notification yet, so we lean on the bike's incidental traffic
// (battery, kickstand, etc.) to keep the screen alive. Default 60s gives
// even a quiet bike plenty of breathing room.
constexpr int   SLEEP_TIMEOUT_DEFAULT_S = 60;
constexpr int   SLEEP_TIMEOUT_MIN_S     = 20;
constexpr int   SLEEP_TIMEOUT_MAX_S     = 300;

// Brightness 1..10 mapped to backlight 25..255.
constexpr int   BRIGHTNESS_DEFAULT = 8;
constexpr int   BRIGHTNESS_MIN     = 1;
constexpr int   BRIGHTNESS_MAX     = 10;
inline int brightness_to_pwm(int b) { return b * 25 + 5; }

// ----- Colors (RGB565 helpers) -----
#define RGB(r,g,b) (((r) & 0xF8) << 8 | ((g) & 0xFC) << 3 | ((b) & 0xF8) >> 3)
namespace Color {
    constexpr uint16_t BG       = RGB( 15,  15,  20);
    constexpr uint16_t PANEL    = RGB( 28,  28,  36);
    constexpr uint16_t FG       = RGB(240, 240, 240);
    constexpr uint16_t DIM      = RGB(110, 110, 120);
    constexpr uint16_t MUTED    = RGB( 60,  60,  70);
    constexpr uint16_t ACCENT   = RGB( 60, 200, 255);
    constexpr uint16_t WARN     = RGB(255,  80,  80);
    constexpr uint16_t OK       = RGB( 60, 220, 100);
    constexpr uint16_t SIGNAL   = RGB(255, 165,   0);
    constexpr uint16_t REEVO_BLUE = RGB(43, 87, 220);   // matches the logo
    constexpr uint16_t SEG_YELLOW = RGB(255, 224,  30);  // 7-seg / calculator yellow
}
#undef RGB

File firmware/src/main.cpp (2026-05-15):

// ----------------------------------------------------------------------------
//  main.cpp — Reevo Dashboard firmware entry point.
//
//  Owns the display + touch hardware. Delegates BLE to ble.cpp and all
//  rendering / touch handling to ui.cpp. This file stays tiny so it's
//  easy to keep in mind.
// ----------------------------------------------------------------------------

#include <Arduino.h>
#include "lgfx_board.h"
#include "state.h"
#include "ble.h"
#include "ui.h"
#include "uart_tap.h"
#include "power.h"
#include "cmd_ap.h"
#include "brake_warn.h"
#include "pas_timeout.h"
#include "secrets.h"
#include "theme.h"
#include "assets.h"
#include "user_config.h"

BikeState g_state;
static LGFX tft;

// ---------------------------------------------------------------------------
//  Touch — LovyanGFX's FT5x06 driver doesn't auto-rotate touch coords,
//  so we pull raw and apply our own rotation-1 transform.
// ---------------------------------------------------------------------------
static inline void touch_transform(int32_t rx, int32_t ry,
                                   int32_t* x, int32_t* y) {
    *x = (PANEL_NATIVE_HEIGHT - 1) - ry;
    *y = rx;
}

static bool get_touch(int32_t* x, int32_t* y) {
    int32_t rx, ry;
    if (!tft.getTouchRaw(&rx, &ry)) return false;
    touch_transform(rx, ry, x, y);
    return true;
}

// ---------------------------------------------------------------------------
//  Splash — shown once at boot
// ---------------------------------------------------------------------------
static void splash() {
    // Blit the bike-art bitmap; the Reevo wordmark is baked in at center.
    tft.pushImage(0, 0, SPLASH_BITMAP_W, SPLASH_BITMAP_H, splash_bitmap);
    // Tagline below the wordmark. White-on-dark sits on the bike art well.
    tft.setFont(&fonts::FreeSans12pt7b);
    tft.setTextDatum(top_center);
    tft.setTextColor(TFT_WHITE, TFT_BLACK);  // BG is dark; antialiased edges blend ok
    tft.drawString(USER_SPLASH_TAGLINE, DISPLAY_WIDTH / 2, 165);
    delay(1500);
}

// ---------------------------------------------------------------------------
//  Setup + loop
// ---------------------------------------------------------------------------
void setup() {
    Serial.begin(115200);
    uint32_t deadline = millis() + 4000;
    while (!Serial && millis() < deadline) delay(10);
    Serial.println();
    Serial.println("[boot] === Reevo dashboard ===");
    Serial.printf("[boot] free heap=%u  free PSRAM=%u\n",
                  ESP.getFreeHeap(), ESP.getFreePsram());

    Serial.println("[boot] tft.init()");
    tft.init();
    Serial.println("[boot] setRotation/setBrightness");
    tft.setRotation(DISPLAY_ROTATION);
    tft.setBrightness(brightness_to_pwm(g_state.brightness));

    Serial.println("[boot] splash()");
    splash();

    Serial.println("[boot] secrets::setup()");
    secrets::setup();

    Serial.println("[boot] theme::setup()");
    theme::setup();

    Serial.println("[boot] ui_setup()");
    ui_setup(&tft);

    Serial.println("[boot] power::setup()");
    power::setup(&tft);

    Serial.println("[boot] uart_tap_setup()");
    uart_tap_setup();

    Serial.println("[boot] cmd_ap::setup()");
    cmd_ap::setup();

    Serial.println("[boot] brake_warn::setup()");
    brake_warn::setup();

    Serial.println("[boot] pas_timeout::setup()");
    pas_timeout::setup();

    Serial.println("[boot] ble_setup()");
    ble_setup();

    Serial.println("[boot] setup() complete — entering loop");
}

void loop() {
    ble_loop();
    uart_tap_loop();
    cmd_ap::loop();
    brake_warn::loop();
    pas_timeout::loop();

    // Touch: dispatch on rising-edge only. Note that ui_on_touch() itself
    // calls power::touch_activity(), so a touch while asleep will wake first
    // and then be processed.
    static bool was_down = false;
    int32_t x, y;
    bool down = get_touch(&x, &y);
    if (down && !was_down) {
        ui_on_touch((int)x, (int)y);
    }
    was_down = down;

    power::loop();
    ui_loop();
    delay(5);
}

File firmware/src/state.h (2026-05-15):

// ----------------------------------------------------------------------------
//  state.h — single source of truth.
//  Bike-side fields are written by ble.cpp from R-* notifications.
//  UI / user settings live here too.
// ----------------------------------------------------------------------------
#pragma once

#include <stdint.h>
#include "config.h"

struct BikeState {
    // ---- Live telemetry mirrored from R-* ----
    float    speed_mph         = 0.0f;     // odometer-derived (legacy)
    uint8_t  battery_pct       = 0;
    uint8_t  battery2_pct      = 0;
    uint8_t  assist_level      = 0;
    bool     headlight_on      = false;
    bool     left_signal       = false;
    bool     right_signal      = false;
    bool     front_brake       = false;
    bool     rear_brake        = false;
    bool     kickstand_down    = false;
    bool     kickstand_locked  = false;
    bool     throttle_enabled  = true;
    // Badge light (EL strip on the head badge). The bike doesn't echo its
    // state in any R-* register we've decoded, so we can't sync at boot —
    // we keep a tri-state and only flip to Known after the user toggles.
    enum class BadgeLight : int8_t { Unknown = -1, Off = 0, On = 1 };
    BadgeLight badge_light = BadgeLight::Unknown;

    // ---- R-2-1 stream ----
    uint16_t wheel_pulse      = 0;
    uint32_t odometer_counter  = 0;
    uint32_t odo_last_ms       = 0;
    // Trip distance baseline. trip_miles = (odo_counter - this) * tick→mile
    // factor. Reset by the rider tapping the trip button on the main screen.
    uint32_t trip_baseline_odo = 0;

    // ---- BLE connection ----
    enum class BleStatus { Idle, Scanning, Connecting, Pairing, Connected, Disconnected };
    BleStatus ble                  = BleStatus::Idle;
    bool      bonded               = false;
    int       reconnect_attempt    = 0;

    // ---- User settings (would be persisted to NVS later) ----
    int   top_speed       = TOP_SPEED_DEFAULT;        // 1..20
    int   sleep_timeout_s = SLEEP_TIMEOUT_DEFAULT_S;  // 20..300
    int   brightness      = BRIGHTNESS_DEFAULT;       // 1..10
    bool  brake_warn_enabled = true;                  // alt-blink + badge on brake hold
    bool  pas_timeout_enabled = true;                 // drop PAS to 0 after 10 min idle

    // ---- Helpers ----
    float displayed_speed() const {
        if (wheel_pulse == 0) return 0.0f;
        float pct = (float)wheel_pulse / MAX_WHEEL_PULSE;
        if (pct > 1.0f) pct = 1.0f;
        return pct * (float)top_speed;
    }
    // Empirical: speed_mph = cps × 0.88 means 1 tick/sec ≈ 0.000244 mi/s.
    // So 1 odo tick ≈ 0.000244 mi.
    float trip_miles() const {
        if (odometer_counter < trip_baseline_odo) return 0.0f;
        return (float)(odometer_counter - trip_baseline_odo) * 0.000244f;
    }
};

extern BikeState g_state;

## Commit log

2026-05-15 Initial open-source release
    ESP32-S3 dashboard firmware for the Beno Reevo hubless e-bike.
    Replaces the (defunct) phone app with a touchscreen that talks to the
    bike over BLE. Targets the Freenove FNK0104B board by default; the
    display profile is editable for other CYDs.
    See README.md for setup, docs/PROTOCOL.md for the BLE reverse-
    engineering notes.
    [ble.cpp, cmd_ap.cpp, config.h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]
2026-05-15 Update README.md
    Clarified certain points about the BLE UART taps and changed intro for accuracy.
2026-05-29 Add 3D-printable screen enclosure (top bezel + bottom shell)
    Two STL files for the Freenove FNK0104B case, plus README references
    in the Hardware section and project layout. Also dedupe the stray
    tools/ entry in the layout tree.
    [Reevo_Screen_Bottom.stl, Reevo_Screen_Top.stl]
2026-05-29 platformio.ini: fix stale board ref, drop hardcoded serial port
    - Target comment said Sunton CYD; the board is a Freenove FNK0104B
    (matches README, display_config.h, and the build narrative).
    - upload_port/monitor_port were pinned to one machine's /dev path,
    which breaks flashing on every other machine. Commented out so
    PlatformIO auto-detects; left as documented opt-in overrides.
2026-05-29 docs: clarify UART tap — power vs data, one-way, on-screen passkey recovery
    - Power tap (5V/GND from labeled mainboard pads) is separate from the
    BLE-debug data tap; both just land on the screen's 4-pin header.
    - The data tap is read-only (module TX -> screen RX); the screen never
    transmits and the cable controls nothing on the bike.
    - Document the screen-native recovery path: the Diagnostics page shows
    the BLE module's printed passkey, so a built dashboard recovers a
    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
2026-05-29 on-device manual: add on-screen passkey recovery via Diagnostics
    Restructure newreevosetup OPTION A into A-1 (read the passkey right on
    the dashboard's Diagnostics page — no computer) and A-2 (USB-UART
    adapter, for before the screen is built). Note the tap is read-only
    and that screen power is a separate 5V/GND pad, not the debug port.
    Requires a reflash to take effect on-device.
2026-05-29 README: add 3D-print recommendations for the enclosure
    Not water-resistant (and don't ride a Reevo in the rain); PLA/PETG are
    both fine for careful, occasional use; reference settings for the NylonX
    build (0.24mm, 3 walls, 25% infill) with its hardened-nozzle/enclosure
    caveat.
2026-08-25 docs: remove two bogus GATT UUIDs
    The "PIN Code Change" and "Fingerprint / Auth" characteristics listed in
    PROTOCOL.md and the firmware's web-console manual don't exist. Both UUIDs
    came from a libapp.so string dump rather than a GATT scan, and are Windows
    KNOWNFOLDERIDs. The bike exposes exactly four characteristics, all under
    the ISSC transparent-UART service.
    Thanks to Marek Żurawski for the finding.
